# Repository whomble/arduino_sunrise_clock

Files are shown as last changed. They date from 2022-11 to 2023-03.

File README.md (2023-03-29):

# arduino_sunrise_clock

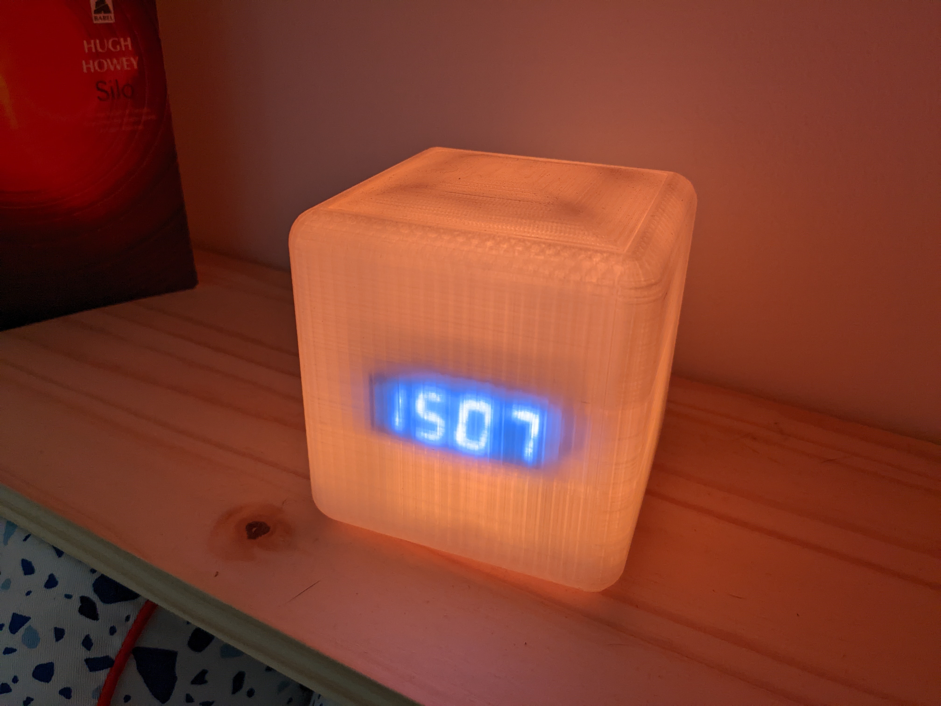
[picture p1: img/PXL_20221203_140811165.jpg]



I made this project to mimic the comercial sunrise clock that you can buy online but cheaper (at least it was cheaper in 2018)

This clock has two mains functions: 
- Anbiant RGB light with a large range of colors
- Sunrise mode which increase light gradually for 30 minutes

There is only one button on the top of the device which is used for:
- Switching ON/OFF the 7 segment display
- Switching OFF the ambiant light 
- Switching OFF the sunrise 

The others settings can be change with the remote control:
- Increse/decrese R G and B independetly and gradually
- Setting the time
- Setting the alarm clock
- Switching ON/OFF the alarm clock
- Switching ON/OFF the ambiant light

# Part list
| Part | Quantity | Cost |
|- | - | - |
| Arduino Nano | 1 | 5€ |
| RTC module | 1 | 3€ |
| RGB led ring | 1 | 4€ |
| USB-C connector | 1 | 1€ |
| 7 segments 4 digits display | 1 | 5€ |
| IR remote + reciever | 1 | 2€ |
| Push button | 4 | 0.1€ |
| Clear filament spool | 1 | 20€ |
| Total | 1 | 20-50€ |

Any RTC module would work but the DS3231 is the more compact and reliable (I've used the DS1307)
When I built this clock the 0.78 inches (high not diagonal) 7 segments display cost something like 3-5€ but I couldn't find any now...
It can be replaced by an OLED screen or a smaller 7segment display 

# 3D printing

The 3D files can be found here [stl](3D/stl) and if you want to change my design the [step files](3D/step) are availlable.

The files are printed in clear filament which isn't clear but can difuse light efficiently.
Since any pieces are under constraint 2-3 wall are enougth but be carrefull to choose the right infil patern because it will be visible from the outside! 
I've choose to use a concentric infill patern for the top piece and a grid for the perimeter but feel free to try something elese (gyroid is a good alternative).

As always, I use 0.16 layer high with adaptative layers enable (0.12-0.2) and support arent needed for the screen holder only the 4 small pins need support from builplate like that:

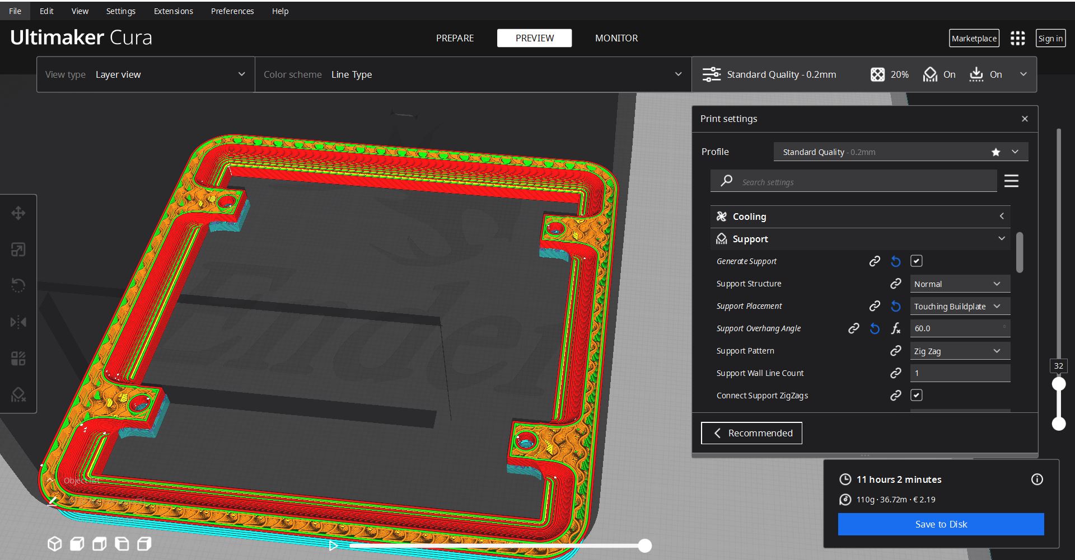
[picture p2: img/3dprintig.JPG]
arduino_sunrise_clock


# Wirring

Since the arduino nano can't deliver much more than 500mA trought the 5V pin and all output conbine, I'll recomande you to connect the 5V and ground of the LED ring and the 7 segment display directly to the USB-C connector.

- RTC clock is connected whith I2c so you just have so solder some wires between SDA - A4 and SCL - A5
- The ring is connected to a pwm output 
- The display is connected to 2 pwm output but depend of the model and can be connected with I2c as well
- The IR reciever is connected to any pin you want
- The push button is connected to a random input pin
- The USB-C breakout board is obviously connected to Vin and Ground and as mentionned before the led ring and the display

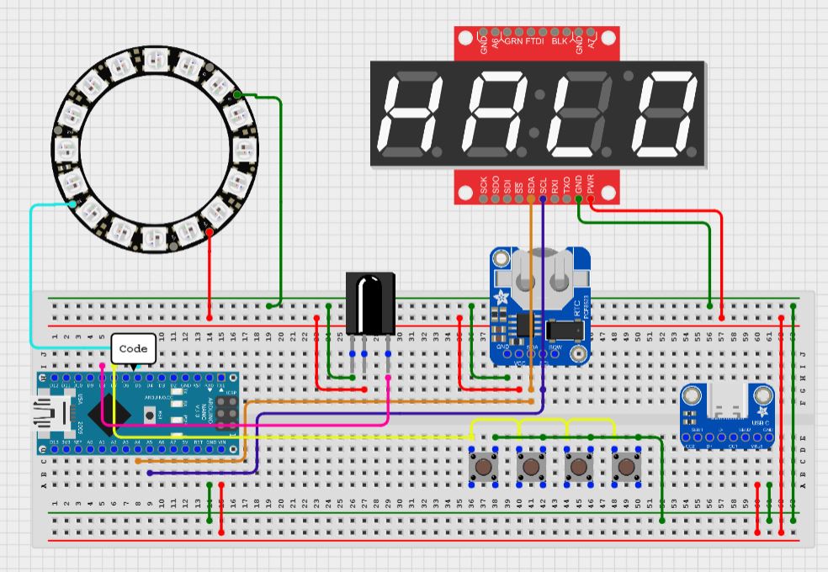
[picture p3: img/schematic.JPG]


# Assembly

All the components should fit easly on the bottom piece, a little bit of hot glue is required to maintain everything in place.

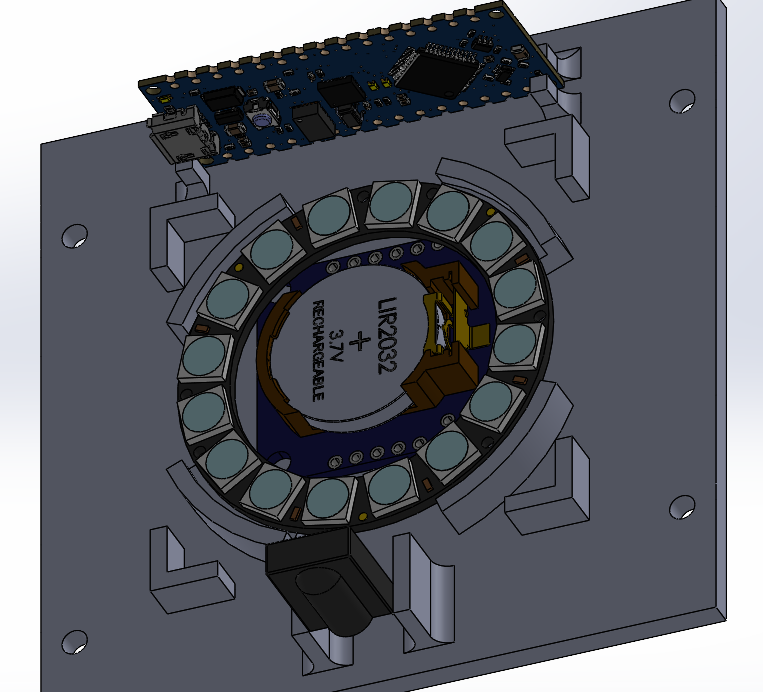
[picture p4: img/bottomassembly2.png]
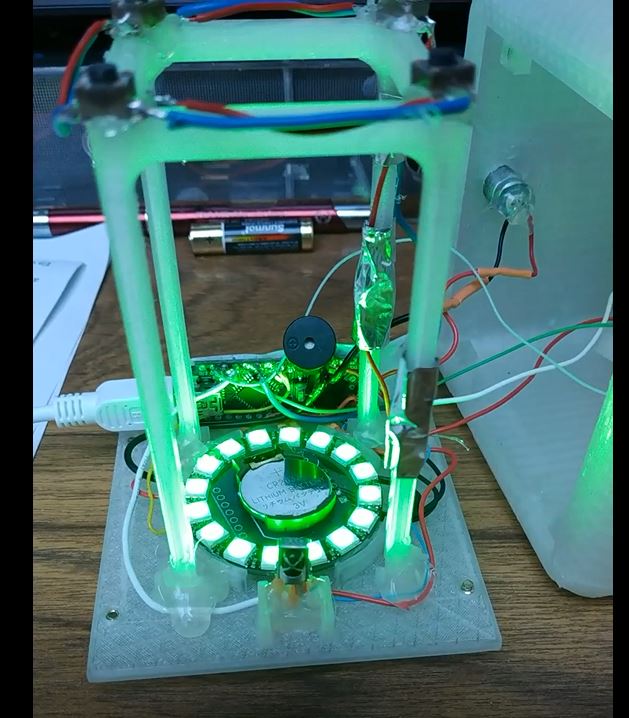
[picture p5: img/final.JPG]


The only tricky part is to place the pushbutton, just place it in the shell upside down and then place the assembly with all the electronics parts

---
# Code

My arduino code is availlable [here](code/horloge.ino) its a mix of french and english and a lots of comments are missing so feel free to contact me if you don't understand something or if it doesn't work!

In theory you would have just two things to change:
- The hex code send by your remote control, you would have to use the IRremote (read) exemple code to record each code (one per button) and then copy the values to my code
- The display script if you are using an OLED or LCD screen instead of the 7 segments.

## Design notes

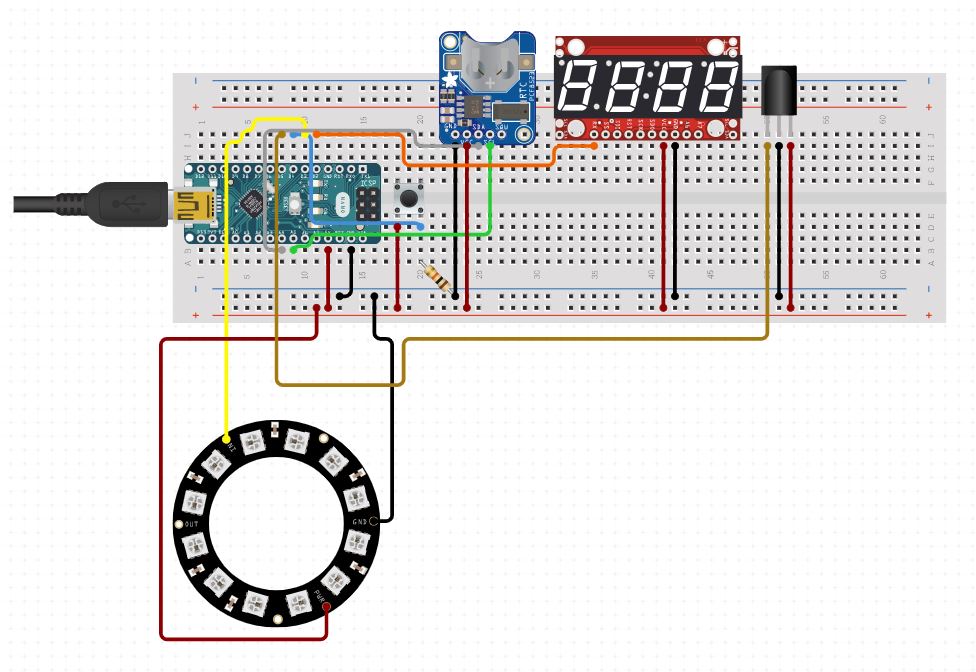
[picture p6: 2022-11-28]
img/Capture.JPG

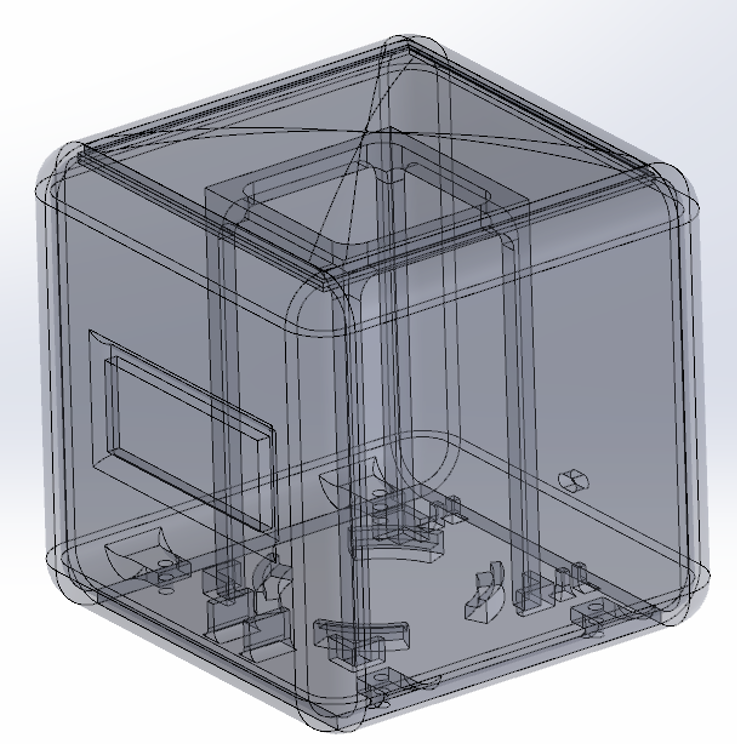
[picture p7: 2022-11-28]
img/solidworks.PNG

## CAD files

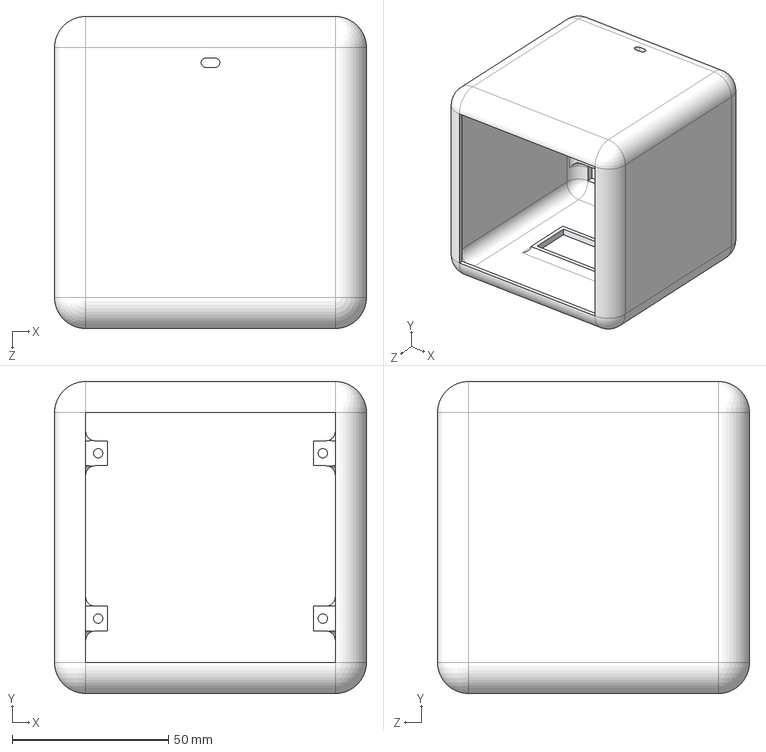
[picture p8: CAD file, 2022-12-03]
3D/step/Carcasse.STEP
100.0 x 100.0 x 100.0 mm

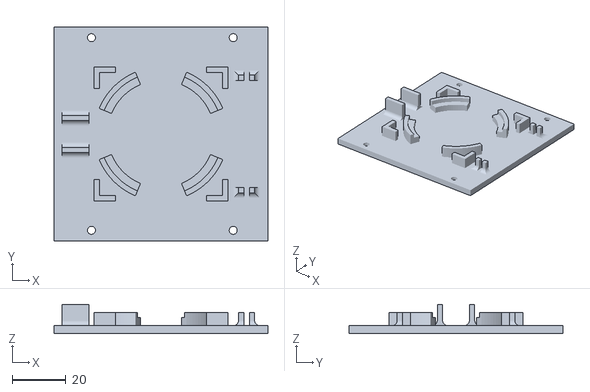
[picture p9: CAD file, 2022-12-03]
3D/stl/basestl.STL
80.0 x 80.0 x 11.0

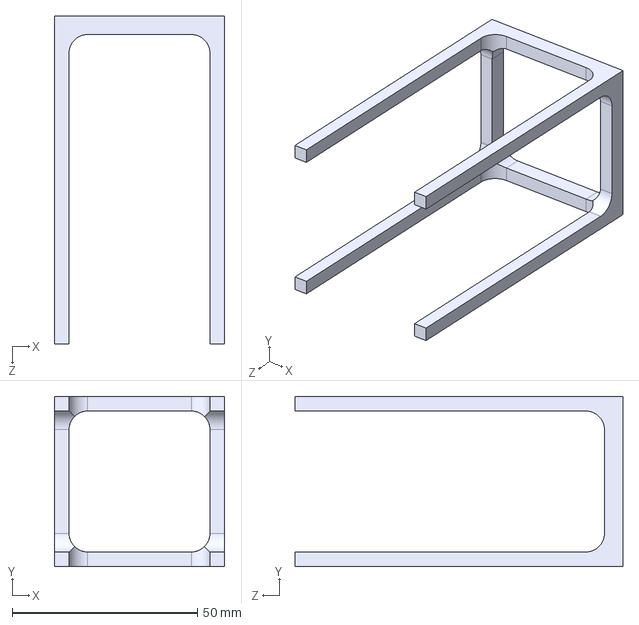
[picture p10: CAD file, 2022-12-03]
3D/step/support boutton.STEP
46.0 x 46.0 x 88.5 mm

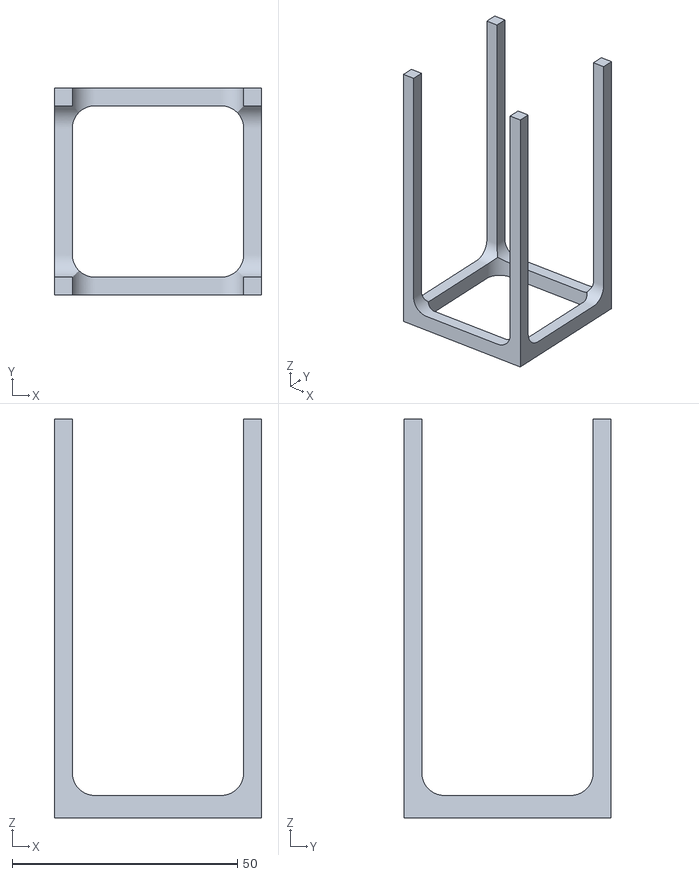
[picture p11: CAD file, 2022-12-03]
3D/stl/support bouttonstl.STL
46.0 x 46.0 x 88.5

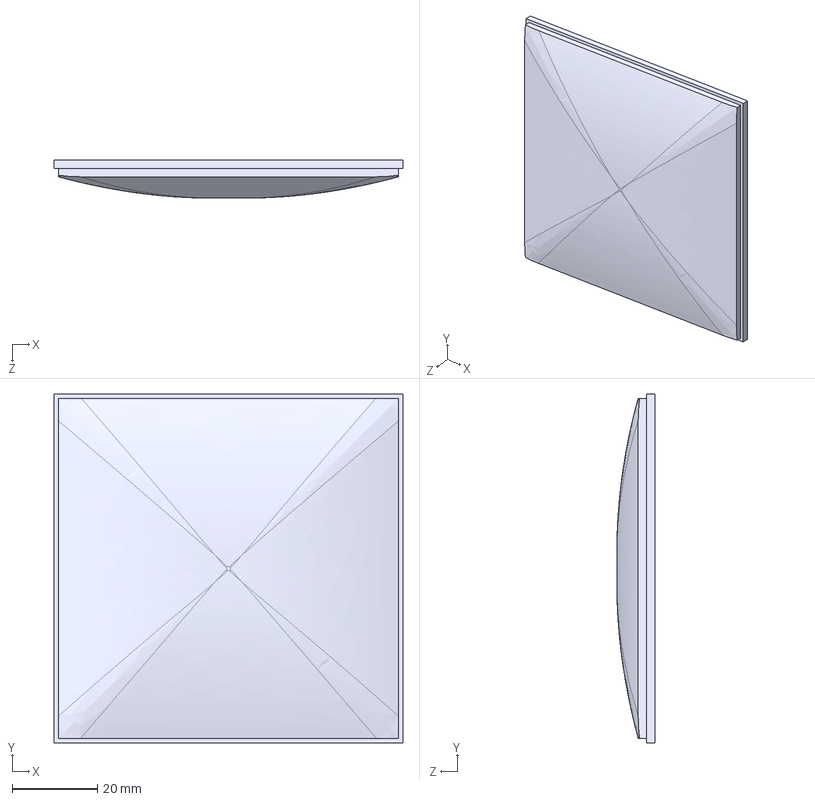
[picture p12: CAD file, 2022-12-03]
3D/step/bouton.STEP
82.0 x 82.0 x 9.03 mm

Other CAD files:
3D/step/base.STEP
3D/stl/CarcasseSTL.STL
3D/stl/boutonstl.STL

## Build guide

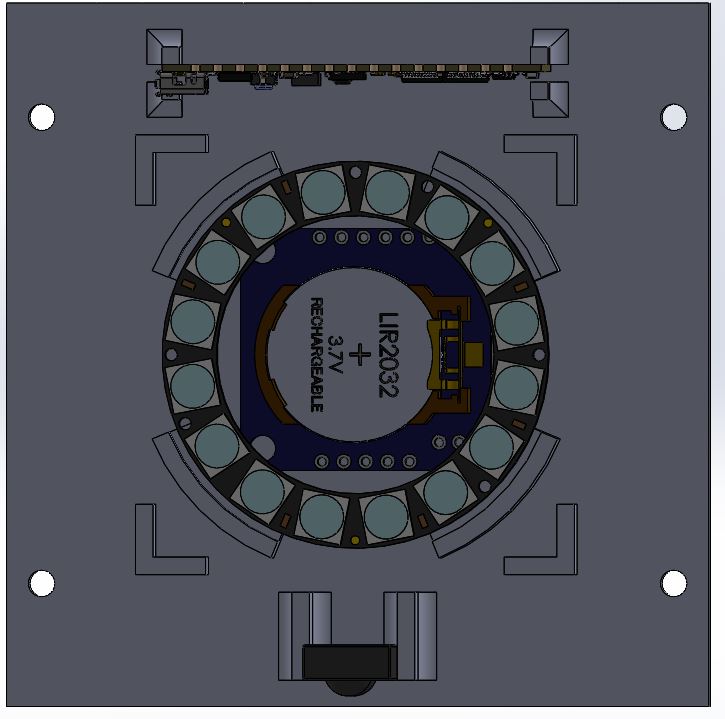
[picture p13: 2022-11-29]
img/bottomassembly.JPG

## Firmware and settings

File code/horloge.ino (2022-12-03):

#include <Wire.h>
#include <RTClib.h>
RTC_DS1307 RTC;
#include <IRremote.h>
#include <Adafruit_NeoPixel.h>
#ifdef __AVR__
#include <avr/power.h>
#endif
#include <Arduino.h>
#include <TM1637Display.h>
#define CLK 6
#define DIO 3
TM1637Display display(CLK, DIO);
int RECV_PIN = 8;
#define PIN            5
#define NUMPIXELS      16
Adafruit_NeoPixel pixels = Adafruit_NeoPixel(NUMPIXELS, PIN, NEO_GRB + NEO_KHZ800);
IRrecv irrecv(RECV_PIN);
decode_results results;
#define buz 9
uint8_t hor, mins, Sec;
int light;
int bright;
int brightOn;
int cligno;
int power1;
int power2;
int power3;
int powerProg1;
int powerProg2;
int powerProg3;
int rate = 0;
int deboutMin;
int deboutHeure;
int bouton;
int color;
int change;
int reglage;
int changeH;
int reglageReveil;
int debout;
bool buzz;
bool night;
int reveilGO;
int argh = 0;
unsigned long currentMillis;
unsigned long previousMillis;
unsigned long interval = 350;
uint8_t segto;
unsigned char ClockPoint = 1;

//diplay time on the 4*7segment display
void affichage(int hor, int mins, int Sec, int brightOn, int bright) {
  display.setBrightness(bright, brightOn);
  display.showNumberDec(hor / 10, false, 1, 0);
  display.showNumberDec(hor % 10, false, 1, 1);
  display.showNumberDec(mins / 10, false, 1, 2);
  display.showNumberDec(mins % 10, false, 1, 3);
}

/* this part of the code increase gradually red green and blue intensity to simulate sunrise
 *  I've choose 3 factor to match the true colors so there is 5 times more green than blue and 2 times more red than blue */
void allumerLedsProg(double rate) {
  for (int i = 0; i < rate / 2; i++)
  {
    powerProg1 = 5 * rate / 2;
    powerProg2 = 2 * rate / 2;
    powerProg3 = 1 * rate / 2;
    pixels.setPixelColor(i, pixels.Color(powerProg1, powerProg2, powerProg3));
    pixels.show();
  }
}
int lumiereAmbiance(int bouton) {

// switching on and off the lights using ether the remote or the push button

  if (bouton == 42 && light == 0) {
    light = 1 ;
    bouton = 999;
  }
  if (bouton == 42 or buzz == 0 && light == 2) {
    light = 0;
    bouton = 999;
    for (int i = 0; i < NUMPIXELS; i++)
    {
      pixels.setPixelColor(i, pixels.Color(0, 0, 0));
      pixels.show();
    }
  }
  if (light == 1) {

    for (int i = 0; i < NUMPIXELS; i++)
    {
      pixels.setPixelColor(i, pixels.Color(power1, power2, power3));
      pixels.show();
    }
    light = 2;
  }
  
  //allow to increase or decrease gradually each color for 0 to 255 (0,1,3,7,15,31,63,127,255)
  
  if (light == 2 && bouton < 7 && bouton > 0) {
    switch (bouton) {
      case 1:
        power1 = ((power1 + 1) * 2) - 1;
        if (power1 > 255) {
          power1 = 255;
        }
        break;
      case 4:
        power1 = ((power1 + 1) / 2) - 1; /* mod 256, -= 5 */
        if (power1 < 0) {
          power1 = 0;
        }
        break;
      case 2:
        power2 = ((power2 + 1) * 2) - 1;
        if (power2 > 255) {
          power2 = 255;
        }
        break;
      case 5:
        power2 = ((power2 + 1) / 2) - 1;
        if (power2 < 0) {
          power2 = 0;
        }
        break;
      case 3:
        power3 = ((power3 + 1) * 2) - 1;
        if (power3 > 255) {
          power3 = 255;
        }
        break;
      case 6:
        power3 = ((power3 + 1) / 2) - 1;
        if (power3 < 0) {
          power3 = 0;
        }
        break;
      default:
        break;
    }
    light = 1;
    bouton = 999;
  }
  return bouton;
}

//if you want to add a buzzer to the device
void buzzer(int dring) {
}

// compare the current time with the alarm

void wakeup(int hor, int mins, int buzz) {
  if (debout == 1) {
    if (hor == deboutHeure && mins == deboutMin) {
      reveilGO = 1;
    }
    if (rate == 31 or buzz == 0) { // switch off the ligths after 30 mins or if the push button has been activated
      for (int i = 0; i < NUMPIXELS; i++)
      {
        pixels.setPixelColor(i, pixels.Color(0, 0, 0));
        pixels.show();
      }
      reveilGO = 0;
      rate = 0;
      buzzer(0);
    }
    if (reveilGO == 1) { // rate is use to define the sunrise speed 
      rate = mins - deboutMin;
      if (rate < 0) {
        rate = rate + 60;
      }
      allumerLedsProg(rate);//if you want the sun to rise in 15 mins instead of 30 you just have to add a *2 before rate
      if (rate == 30) {
        buzzer(1);
      }
    }
  }
}

//Recieve and harvest the data from IR sensor and associate each button to a value, to find your remote value, just use the IR Remote exemple and replace the hex data
int IR() {
  if (irrecv.decode(&results)) {
    irrecv.resume();
    switch (results.value % 0x10000) {
      case 0x6897:
        bouton = 0;
        break;
      case 0x30CF:
        bouton = 1;
        break;
      case 0x18E7:
        bouton = 2;
        break;
      case 0x7A85:
        bouton = 3;
        break;
      case 0x10EF:
        bouton = 4;
        break;
      case 0x38C7:
        bouton = 5;
        break;
      case 0x5AA5:
        bouton = 6;
        break;
      case 0x42BD:
        bouton = 7;
        break;
      case 0x4AB5:
        bouton = 8;
        break;
      case 0x52AD:
        bouton = 9;
        break;
      case 0xA25D:
        bouton = 42; //off
        break;
      case 0x629D:
        bouton = 74; //vol+
        break;
      case 0xA857:
        bouton = 38; //vol-
        break;
      case 0x9867:
        bouton = 714; //EQ
        break;
      case 0xC23D:
        reglage = 1; //>>
        break;
      case 0x22DD:
        reglage = 0; //<<
        break;
      case 0xB04F:
        bouton = 333; //st rept
        break;
      case 0x02FD:
        bouton = 222; //st rept
        break;
      default:
        break;
    }
  }
  return bouton;
}

//Set time, the << and >> button on my remote alow to switch from min to hour and the +/- increment or decrement the value, feel free to just have a button for each function

void times(int hor, int mins, int changeH) {
  if (changeH == 1) {
    if (reglage == 0) {
      if (bouton == 74)
        hor++;
      else if (bouton == 38)
        hor += 23;
      hor %= 24;
    }
    else {
      if (bouton == 74)
        mins++;
      else if (bouton == 38)
        mins--;
      if (mins == 60) {
        hor++;
        hor %= 24;
        mins = 0;
      }
      else if (mins == -1) {
        hor += 23;
        hor %= 24;
        mins = 59;
      }
    }
    RTC.adjust(DateTime(2017, 9, 17, hor, mins, 0)); //Save the value to the RTC, since the seconds and the date isn't display on my clock I've set a random date
  }
}

// same as befor but for the alarm clock

int setReveil(int reglageReveil) {
  if (reglageReveil == 1) {
    if (reglage == 0) {
      if (bouton == 74)
        deboutHeure++;
      else if (bouton == 38)
        deboutHeure += 23;
      deboutHeure %= 24;
    }
    else {
      if (bouton == 74)
        deboutMin++;
      else if (bouton == 38)
        deboutMin--;
      if (deboutMin == 60) {
        deboutHeure++;
        deboutHeure %= 24;
        deboutMin = 0;
      }
      else if (deboutMin == -1) {
        deboutHeure += 23;
        deboutHeure %= 24;
        deboutMin = 59;
      }
    }
  }
  return (999);
}

//Switch of the display at night
int nuit (int hor, int brightOn) {
  if ((22 <= hor or hor <= 10) && night == 0) {
    brightOn = 0;
    night = 1;
  }
  else if ((10 < hor and hor < 22) && night == 1)
  {
    brightOn = 1;
    night = 0;
  }
  return  brightOn;
}

void setup()
{
  Serial.begin(9600);
  Serial.println("Enabling IRin");
  irrecv.enableIRIn(); // Start the receiver
  Serial.println("Enabled IRin");
  Wire.begin();
  RTC.begin();
#if defined (__AVR_ATtiny85__)
  if (F_CPU == 16000000) clock_prescale_set(clock_div_1);
#endif
  pixels.begin();
  if (!RTC.isrunning())
  {
    RTC.adjust(DateTime(__DATE__, __TIME__));
  }
  RTC.adjust(DateTime(__DATE__, __TIME__));
  for (int i = 0; i < NUMPIXELS; i++)

  {
    pixels.setPixelColor(i, pixels.Color(0, 0, 0));
    pixels.show();
  }
  power1 = 0;
  power2 = 0;
  power3 = 0;
  powerProg1 = 0;
  powerProg2 = 0;
  powerProg3 = 0;
  light = 0;
  change = 0;
  color = 1;
  reglage = 0;
  changeH = 0;
  deboutHeure = 0;
  deboutMin = 0;
  reglageReveil = 0;
  reveilGO = 0;
  debout = 0;
  pinMode (7, INPUT_PULLUP);
  pinMode(9, OUTPUT);
}
void loop()
{
  // Read time from the real time clock
  DateTime now = RTC.now();
  Sec = now.second();
  hor = now.hour();
  mins = now.minute();
  buzz = digitalRead (7);
  
  bouton = IR();// detect if the remote is used and read the value and call the function to set time
  if (bouton == 714) {
    if (changeH == 0) {
      reglageReveil = 0;
      changeH = 1;
    }
    else if (changeH == 1) {
      changeH = 0;
    }
  }
  times(hor, mins, changeH);
  if (bouton == 333) {
    if (reglageReveil == 0) {
      reglageReveil = 1;
      changeH = 0;
    }
    else if (reglageReveil == 1) {
      reglageReveil = 0;
    }
  }
  // if we change the time, the display blink
  if (reglageReveil == 0) {
    if (changeH == 1) {
      currentMillis = millis();
      if ( abs(currentMillis - previousMillis) >= interval) {
        previousMillis = currentMillis;
        if (cligno == 1) {
          affichage(hor, mins, Sec, 1, 1);
          cligno = 0;
          interval = 500;
        }
        else {
          affichage(hor, mins, Sec, 1, bright);
          cligno = 1;
          interval = 500;
        }
      }
    }
    else if (changeH == 0) {

      affichage(hor, mins, Sec, brightOn, bright);
    }
  }
  //same for the alarm clock
  else if (reglageReveil == 1) {
    currentMillis = millis();
    if (abs(currentMillis - previousMillis) >= interval) {
      previousMillis = currentMillis;
      if (cligno == 1) {
        affichage(deboutHeure, deboutMin, 1, 1, 1);
        cligno = 0;
        interval = 500;
      }
      else {
        affichage(deboutHeure, deboutMin, 1, 1, bright);
        cligno = 1;
        interval = 500;
      }
    }
  }
  // enable/disable the alarm clock ( the clock blink one time in red when off and in green when on)
  if (bouton == 222) {
    if (debout == 0) {
      debout = 1;

      for (int i = 0; i < NUMPIXELS; i++)
      {
        pixels.setPixelColor(i, pixels.Color(0, 50, 0));
        pixels.show();
      }
    }
    else if (debout == 1) {
      debout = 0;

      for (int i = 0; i < NUMPIXELS; i++)
      {
        pixels.setPixelColor(i, pixels.Color(50, 0, 0));
        pixels.show();
      }

    }
    delay(200);

    for (int i = 0; i < NUMPIXELS; i++)
    {
      pixels.setPixelColor(i, pixels.Color(0, 0, 0));
      pixels.show();
    }
  }

  // decrease brightness during night
  if (22 <= hor or hor <= 10) {
    bright = 1;
  }
  else if (10 < hor < 22)
  {
    bright = 7;
  }
  if (buzz == 0) {
    brightOn = 1 - brightOn;
    delay(100);
  }
  bouton = setReveil(reglageReveil);
  bouton = IR();
  bouton = lumiereAmbiance(bouton);
  brightOn = nuit (hor, brightOn);
  wakeup(hor, mins, buzz);
}

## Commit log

2022-11-28 Create Schematic
2022-12-03 Create arduino
2022-12-03 Create stl
